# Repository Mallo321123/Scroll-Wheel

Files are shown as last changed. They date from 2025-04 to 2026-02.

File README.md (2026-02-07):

# 🖱️ High-Resolution Scroll Wheel

> A large, high-resolution scroll wheel inspired by [Engineer Bo](https://www.patreon.com/c/engineerbo/posts)'s [YouTube video](https://www.youtube.com/watch?v=FSy9G6bNuKA).

---

## [Documentation](https://wiki.mariolanghammer.de/en/Projects/Scroll-Wheel)

---

> ⚠️ **Early Development Phase**  
> This project is still under development. Use at your own risk.

---

## 📅 Roadmap

- [X] BLE HID Support
- [ ] Mouse Wheel Click Functionality
- [ ] Automatic power off
- [ ] Battery Level tuning
- [ ] Enclosure refinements
- [ ] Scroll acceleration modes

---

## 🔧 Hardware Overview

- **Main Controller:** ESP32 (subject to maybe change later)
- **Magnetic Encoder:** [AS5600](https://ams-osram.com/products/sensor-solutions/position-sensors/ams-as5600-position-sensor)
- **Battery Pack:** S3P2 NiMH Eneloop cells

---

## 💻 Software Architecture

The entire functionality is now handled by a single **ESP32 microcontroller** using **BLE HID** (Human Interface Device) mode.

- The scroll wheel inputs are directly interpreted by the ESP32.
- Input data (e.g. rotation) is sent over **Bluetooth Low Energy** as **HID events**, emulating a native scroll device.
- No additional driver or software is needed on the PC — it works like a standard Bluetooth mouse/scroll input.

> ✅ This simplifies the setup significantly and increases compatibility across Linux, Windows, and macOS.

---

## 🧩 Required Components

| Part | Quantity |
|---|---|
| Main PCB (pre-soldered) | 1 |
| Bearing (65×85×10 mm) | 1 |
| JST GH Cable Kit | 1 set |
| Cylinder Magnets (3×12 mm) | 7 |
| 3D-Printed Parts | 3 |
| S3P2 NiMH Battery Pack | 1 |
| M2×5 Screws | 5 |

---

## 🛠️ Build Guide

### 🔄 Bearing Preparation

Factory bearings may feel stiff due to thick grease. Here's how to optimize smoothness:

1. Remove both sealing rings.
2. Soak the bearing in **isopropyl alcohol** (or another grease remover).
3. Scrub out all remaining grease.
4. Let it dry for ~3 hours.
5. Reinstall **one** sealing ring.
6. Add **light machine oil** generously into the bearing.
7. Reinstall the **second** sealing ring.
8. Spin the bearing multiple times to distribute the oil.
9. *(Optional)* Remove the seals again for an even smoother feel (at the cost of dust protection).

---

## 🚧 Development Gallery

### 🔌 First PCB Prototype (with known bugs)
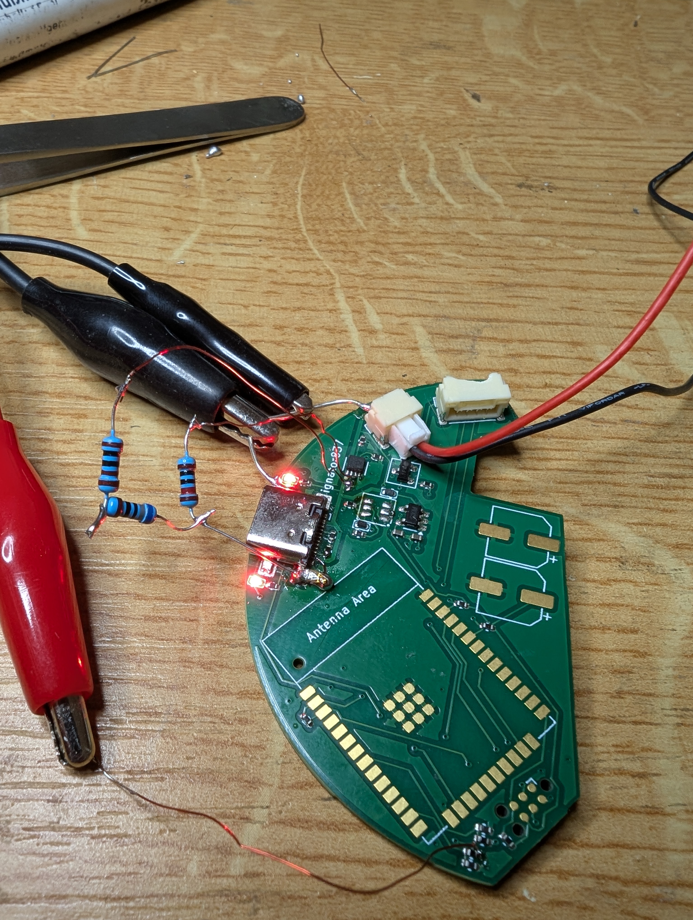
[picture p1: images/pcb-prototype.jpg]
First PCB prototype


---

### 🧱 PCB Inside the Case
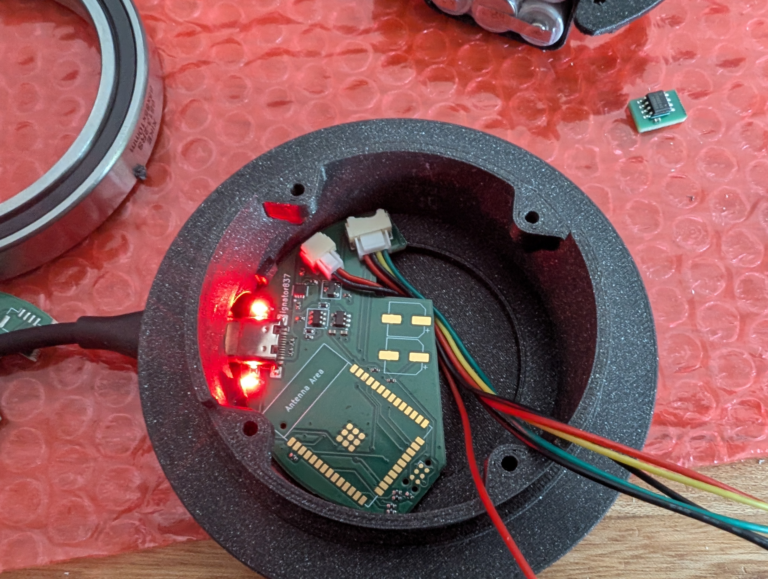
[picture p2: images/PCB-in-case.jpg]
PCB Prototype in case


---

### 🧪 First Firmware Test (External ESP32)
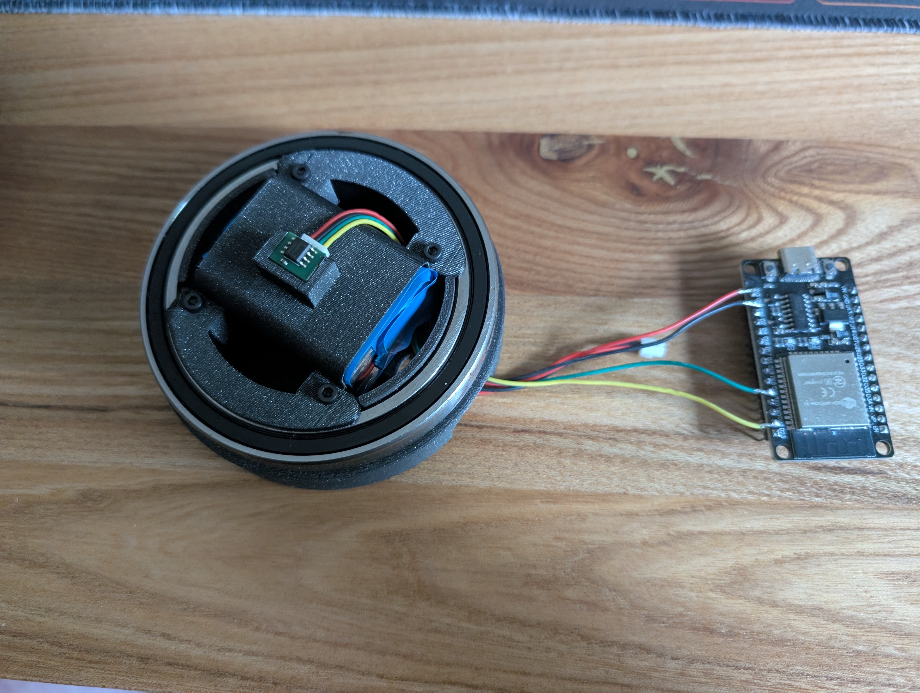
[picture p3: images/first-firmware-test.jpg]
Firmware test


---

### 🧰 Fully Assembled PCB
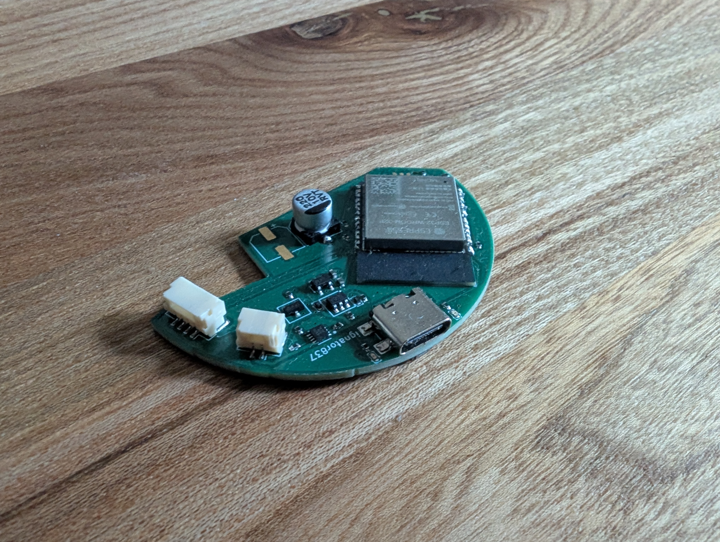
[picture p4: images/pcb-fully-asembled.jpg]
PCB Assembled


---

### 🆕 PCB V2 – Improved & Debugged
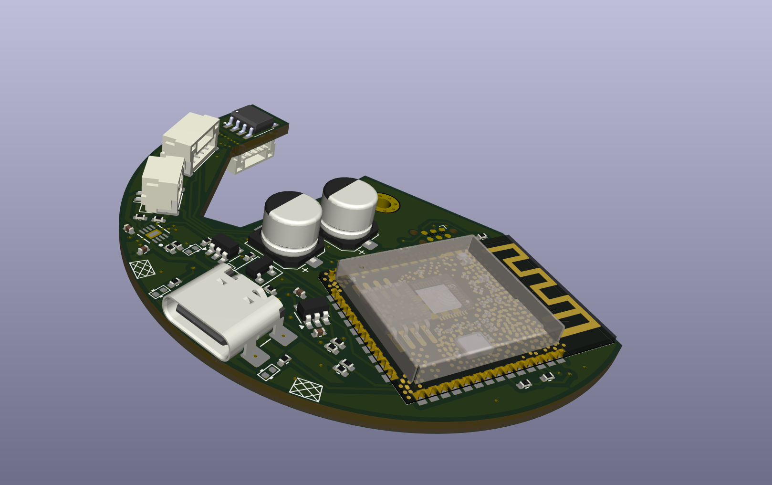
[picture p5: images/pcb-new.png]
PCB V2


---

## 🤝 Contributing

Pull requests, suggestions, and feedback are always welcome — feel free to get involved and help improve the project!  
Prototyping and hardware development can get expensive quickly, so if you’d like to support the project financially:

<a href="https://www.paypal.me/MarioLanghammer" target="_blank">
  
</a>
&nbsp;
<a href="https://ko-fi.com/mallo321123" target="_blank">
  
</a>

Every bit helps keep the ideas (and soldering irons) running!

## Credits
Credits to [T-vk](https://github.com/T-vK) for creating the [ESP32 BLE Mouse](https://github.com/T-vK/ESP32-BLE-Mouse) Library

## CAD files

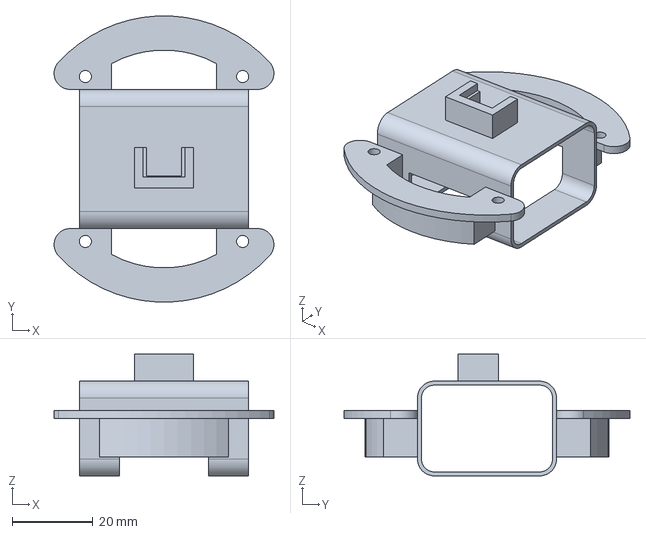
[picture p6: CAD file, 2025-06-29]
CAD/Component Bracket.step
54.5 x 70.9 x 30.2 mm

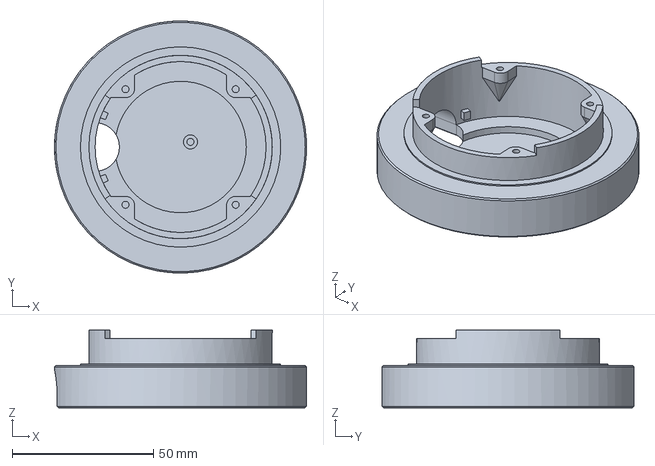
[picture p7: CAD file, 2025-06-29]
CAD/Bottom.step
89.3 x 89.4 x 27.5 mm

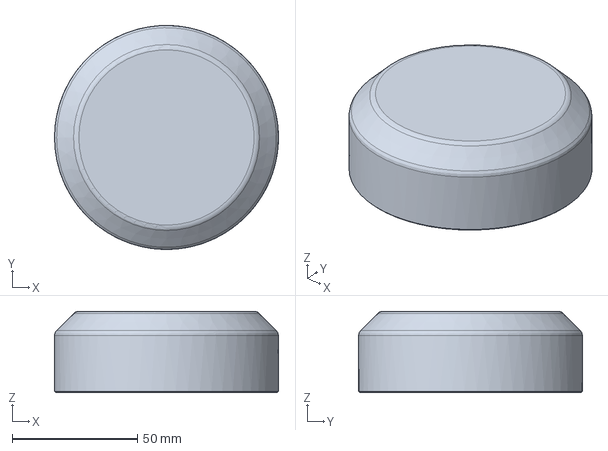
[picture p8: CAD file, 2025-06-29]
CAD/Cap.step
89.4 x 89.4 x 32.5 mm

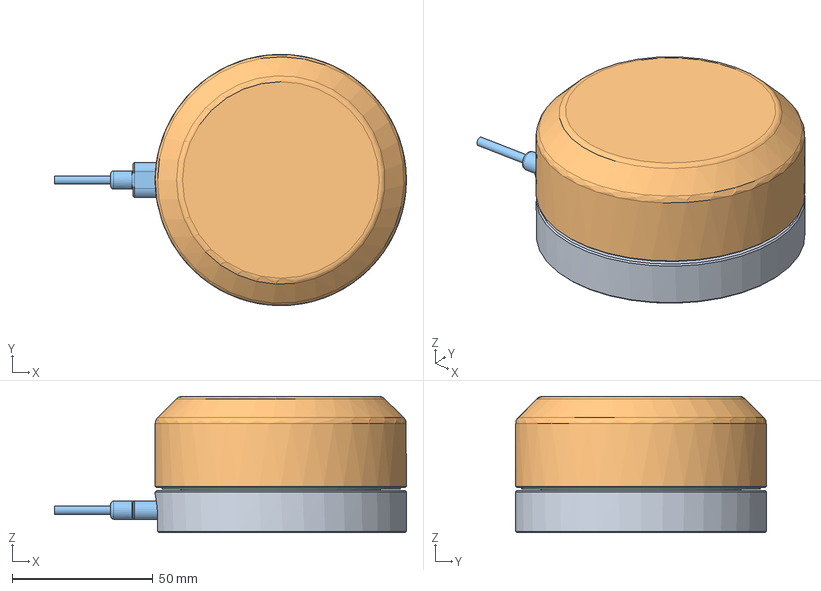
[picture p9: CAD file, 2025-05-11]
CAD/Body.FCStd
125.2 x 89.4 x 48.5 mm
Bottom
Cap
USB-Kabel
Bearing
R_0402_1005Metric
R_0402_1005Metric001
R_0402_1005Metric002
R_0402_1005Metric003
R_0402_1005Metric004
JST_GH_SM02B-GHS-TB_1x02-1MP_P1.25mm_Horizontal
R_0402_1005Metric005
R_0402_1005Metric006
SOT-23-5
R_0402_1005Metric007
DIO_RB161QS_ROM
DIO_RB161QS_ROM001
DIO_RB161QS_ROM002
DIO_RB161QS_ROM003
R_0402_1005Metric008
R_0402_1005Metric009
C_0402_1005Metric
CP_Elec_6.3x5.4
C_0402_1005Metric001
C_0402_1005Metric002
R_0402_1005Metric010
R_0402_1005Metric011
R_0402_1005Metric012
BODY-SON
R_0402_1005Metric013
AS5600
AS5601
AS5602
AS5603
AS5604
AS5605
AS5606
AS5607
AS5608
AS5609
SOT-23-6
R_0402_1005Metric014
R_0402_1005Metric015
JST_GH_SM04B-GHS-TB_1x04-1MP_P1.25mm_Horizontal
CP_Elec_6.3x5.005
DIO_RB161QS_ROM005
DIO_RB161QS_ROM006
DIO_RB161QS_ROM007
DIO_RB161QS_ROM008
R_0402_1005Metric016
SOT-23
R_0402_1005Metric017
USB_C_Receptacle_16P_TopMnt_Horizontal_GCT_USB4105-xx-A037
USB_C_Receptacle_16P_TopMnt_Horizontal_GCT_USB4105-xx-A038
USB_C_Receptacle_16P_TopMnt_Horizontal_GCT_USB4105-xx-A039
USB_C_Receptacle_16P_TopMnt_Horizontal_GCT_USB4105-xx-A040
USB_C_Receptacle_16P_TopMnt_Horizontal_GCT_USB4105-xx-A041
USB_C_Receptacle_16P_TopMnt_Horizontal_GCT_USB4105-xx-A042
USB_C_Receptacle_16P_TopMnt_Horizontal_GCT_USB4105-xx-A043
USB_C_Receptacle_16P_TopMnt_Horizontal_GCT_USB4105-xx-A044
USB_C_Receptacle_16P_TopMnt_Horizontal_GCT_USB4105-xx-A045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

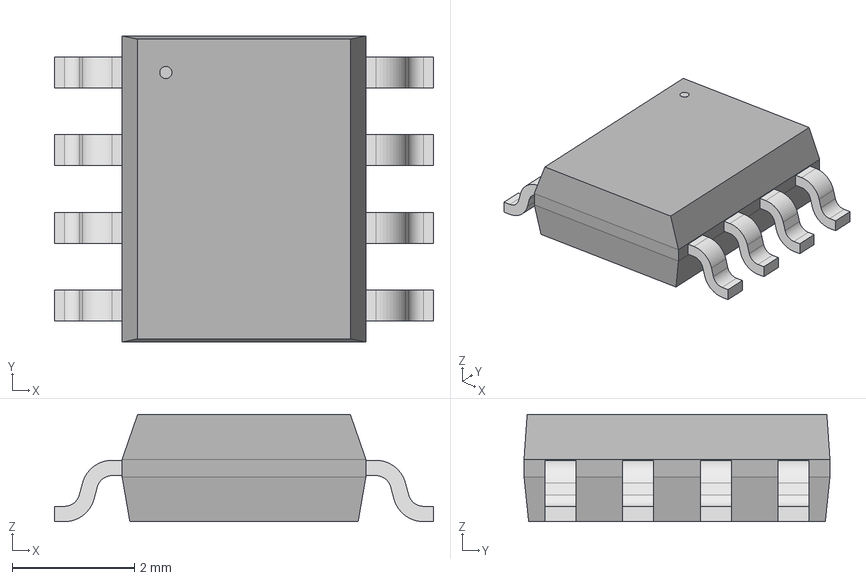
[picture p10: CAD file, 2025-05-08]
PCB/Librarys/3d/SO_ADY-T1-GE3_VIS.step
6.20 x 5.00 x 1.75 mm

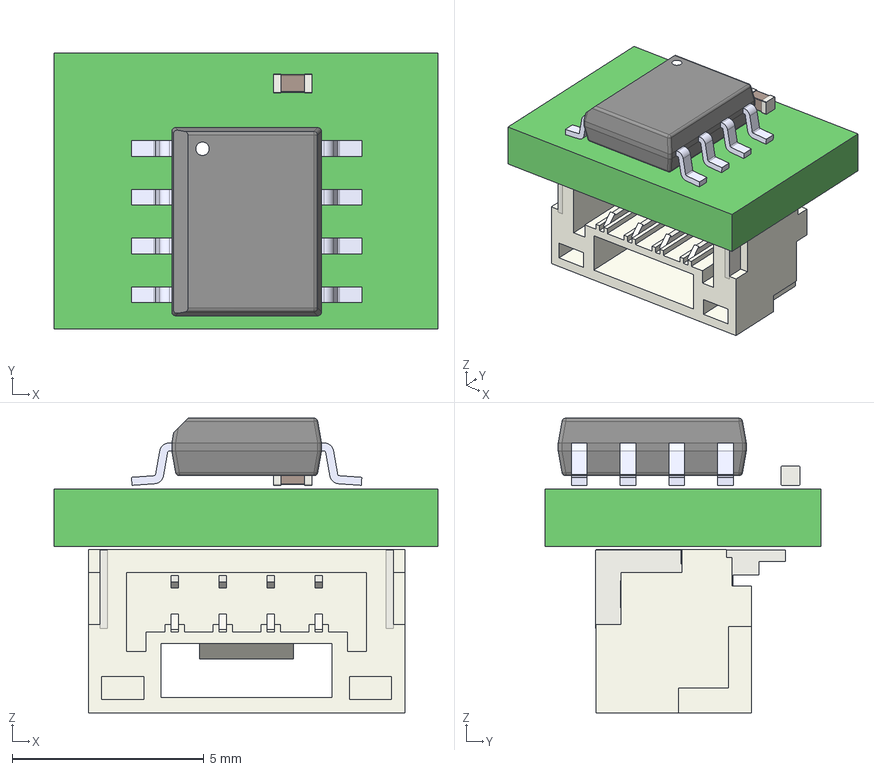
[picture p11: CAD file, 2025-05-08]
CAD/Encoder PCB.step
10.0 x 7.20 x 7.68 mm
C_0402_1005Metric001
AS5600
AS5601
AS5602
AS5603
AS5604
AS5605
AS5606
AS5607
AS5608
AS5609
JST_GH_SM04B-GHS-TB_1x04-1MP_P1.25mm_Horizontal001
Körper

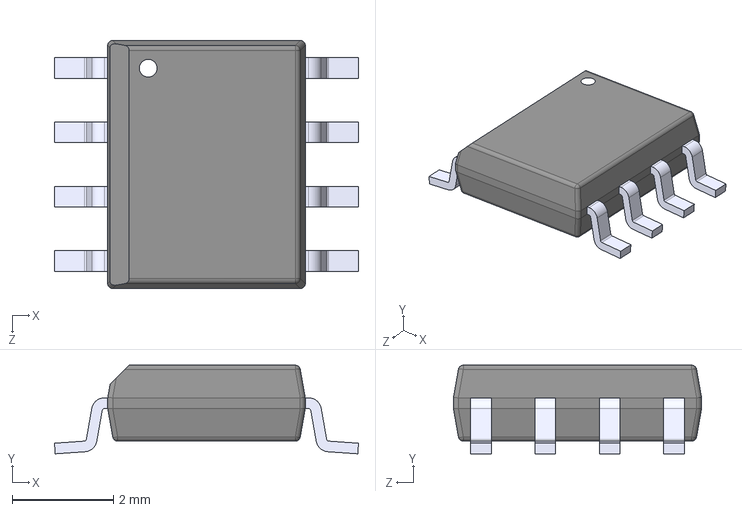
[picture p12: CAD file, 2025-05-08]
PCB/Librarys/3d/AS5600.step
6.00 x 1.75 x 4.90 mm

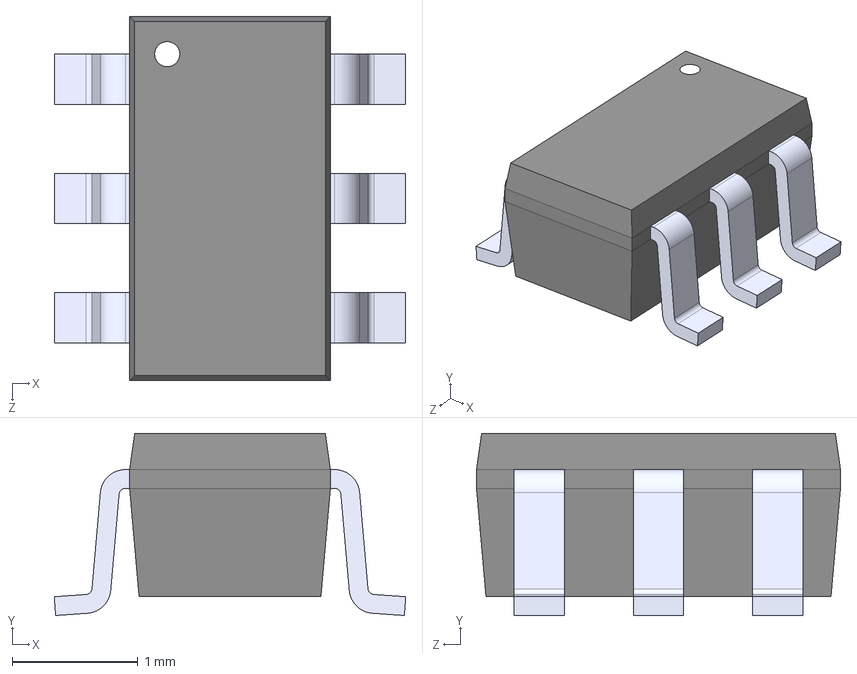
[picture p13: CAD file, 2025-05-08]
PCB/Librarys/3d/FS8205--3DModel.STEP
2.80 x 1.45 x 2.90 mm

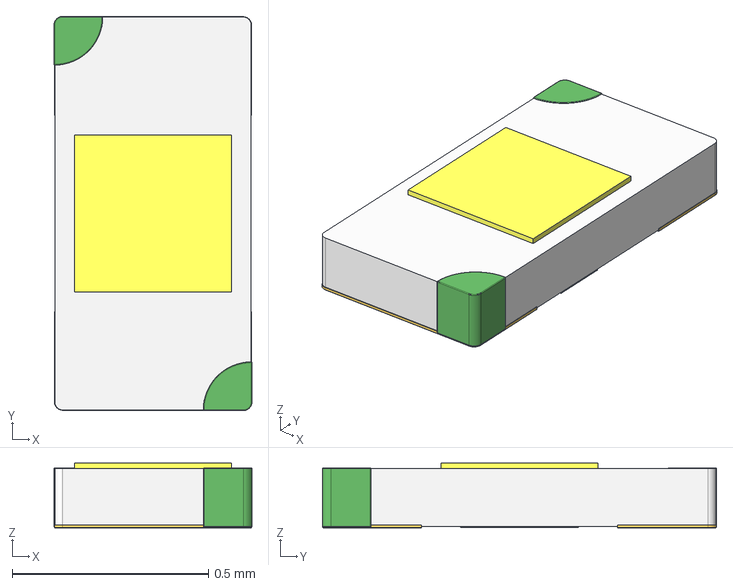
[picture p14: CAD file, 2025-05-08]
PCB/Librarys/3d/ChipLedWith-Yellow.stp
0.504 x 1.00 x 0.165 mm

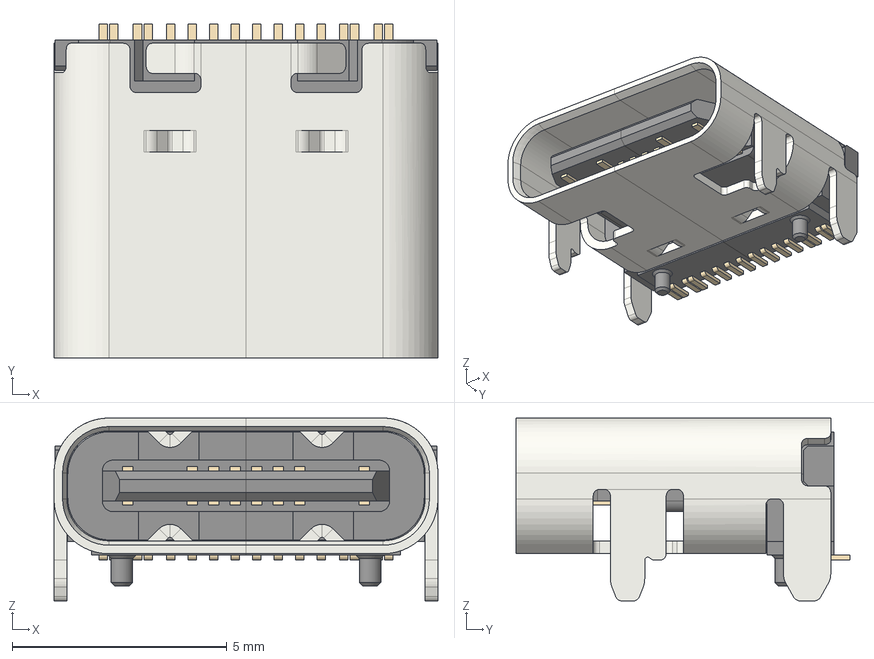
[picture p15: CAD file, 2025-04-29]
PCB/Librarys/3d/USB-C.step
8.94 x 7.78 x 4.26 mm
USB_C_Receptacle_16P_TopMnt_Horizontal_GCT_USB4105-xx-A037
USB_C_Receptacle_16P_TopMnt_Horizontal_GCT_USB4105-xx-A038
USB_C_Receptacle_16P_TopMnt_Horizontal_GCT_USB4105-xx-A039
USB_C_Receptacle_16P_TopMnt_Horizontal_GCT_USB4105-xx-A040
USB_C_Receptacle_16P_TopMnt_Horizontal_GCT_USB4105-xx-A041
USB_C_Receptacle_16P_TopMnt_Horizontal_GCT_USB4105-xx-A042
USB_C_Receptacle_16P_TopMnt_Horizontal_GCT_USB4105-xx-A043
USB_C_Receptacle_16P_TopMnt_Horizontal_GCT_USB4105-xx-A044
USB_C_Receptacle_16P_TopMnt_Horizontal_GCT_USB4105-xx-A045
USB_C_Receptacle_16P_TopMnt_Horizontal_GCT_USB4105-xx-A046
USB_C_Receptacle_16P_TopMnt_Horizontal_GCT_USB4105-xx-A047
USB_C_Receptacle_16P_TopMnt_Horizontal_GCT_USB4105-xx-A048
USB_C_Receptacle_16P_TopMnt_Horizontal_GCT_USB4105-xx-A049
USB_C_Receptacle_16P_TopMnt_Horizontal_GCT_USB4105-xx-A050
USB_C_Receptacle_16P_TopMnt_Horizontal_GCT_USB4105-xx-A051
USB_C_Receptacle_16P_TopMnt_Horizontal_GCT_USB4105-xx-A052
USB_C_Receptacle_16P_TopMnt_Horizontal_GCT_USB4105-xx-A053
USB_C_Receptacle_16P_TopMnt_Horizontal_GCT_USB4105-xx-A054
USB_C_Receptacle_16P_TopMnt_Horizontal_GCT_USB4105-xx-A055
USB_C_Receptacle_16P_TopMnt_Horizontal_GCT_USB4105-xx-A056
USB_C_Receptacle_16P_TopMnt_Horizontal_GCT_USB4105-xx-A057
USB_C_Receptacle_16P_TopMnt_Horizontal_GCT_USB4105-xx-A058
USB_C_Receptacle_16P_TopMnt_Horizontal_GCT_USB4105-xx-A059
USB_C_Receptacle_16P_TopMnt_Horizontal_GCT_USB4105-xx-A060
USB_C_Receptacle_16P_TopMnt_Horizontal_GCT_USB4105-xx-A061
USB_C_Receptacle_16P_TopMnt_Horizontal_GCT_USB4105-xx-A062
USB_C_Receptacle_16P_TopMnt_Horizontal_GCT_USB4105-xx-A063
USB_C_Receptacle_16P_TopMnt_Horizontal_GCT_USB4105-xx-A064
USB_C_Receptacle_16P_TopMnt_Horizontal_GCT_USB4105-xx-A065
USB_C_Receptacle_16P_TopMnt_Horizontal_GCT_USB4105-xx-A066
USB_C_Receptacle_16P_TopMnt_Horizontal_GCT_USB4105-xx-A067
USB_C_Receptacle_16P_TopMnt_Horizontal_GCT_USB4105-xx-A068
USB_C_Receptacle_16P_TopMnt_Horizontal_GCT_USB4105-xx-A069
USB_C_Receptacle_16P_TopMnt_Horizontal_GCT_USB4105-xx-A070
USB_C_Receptacle_16P_TopMnt_Horizontal_GCT_USB4105-xx-A071
USB_C_Receptacle_16P_TopMnt_Horizontal_GCT_USB4105-xx-A072

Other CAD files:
PCB/Librarys/3d/TS-1088-AR02016--3DModel-STEP-269445.STEP
PCB/Librarys/3d/DSG0008A.stp
PCB/Librarys/3d/DIO_RB161QS_ROM.step
CAD/Bottom.stl
CAD/Cap.stl
CAD/Component Bracket.stl

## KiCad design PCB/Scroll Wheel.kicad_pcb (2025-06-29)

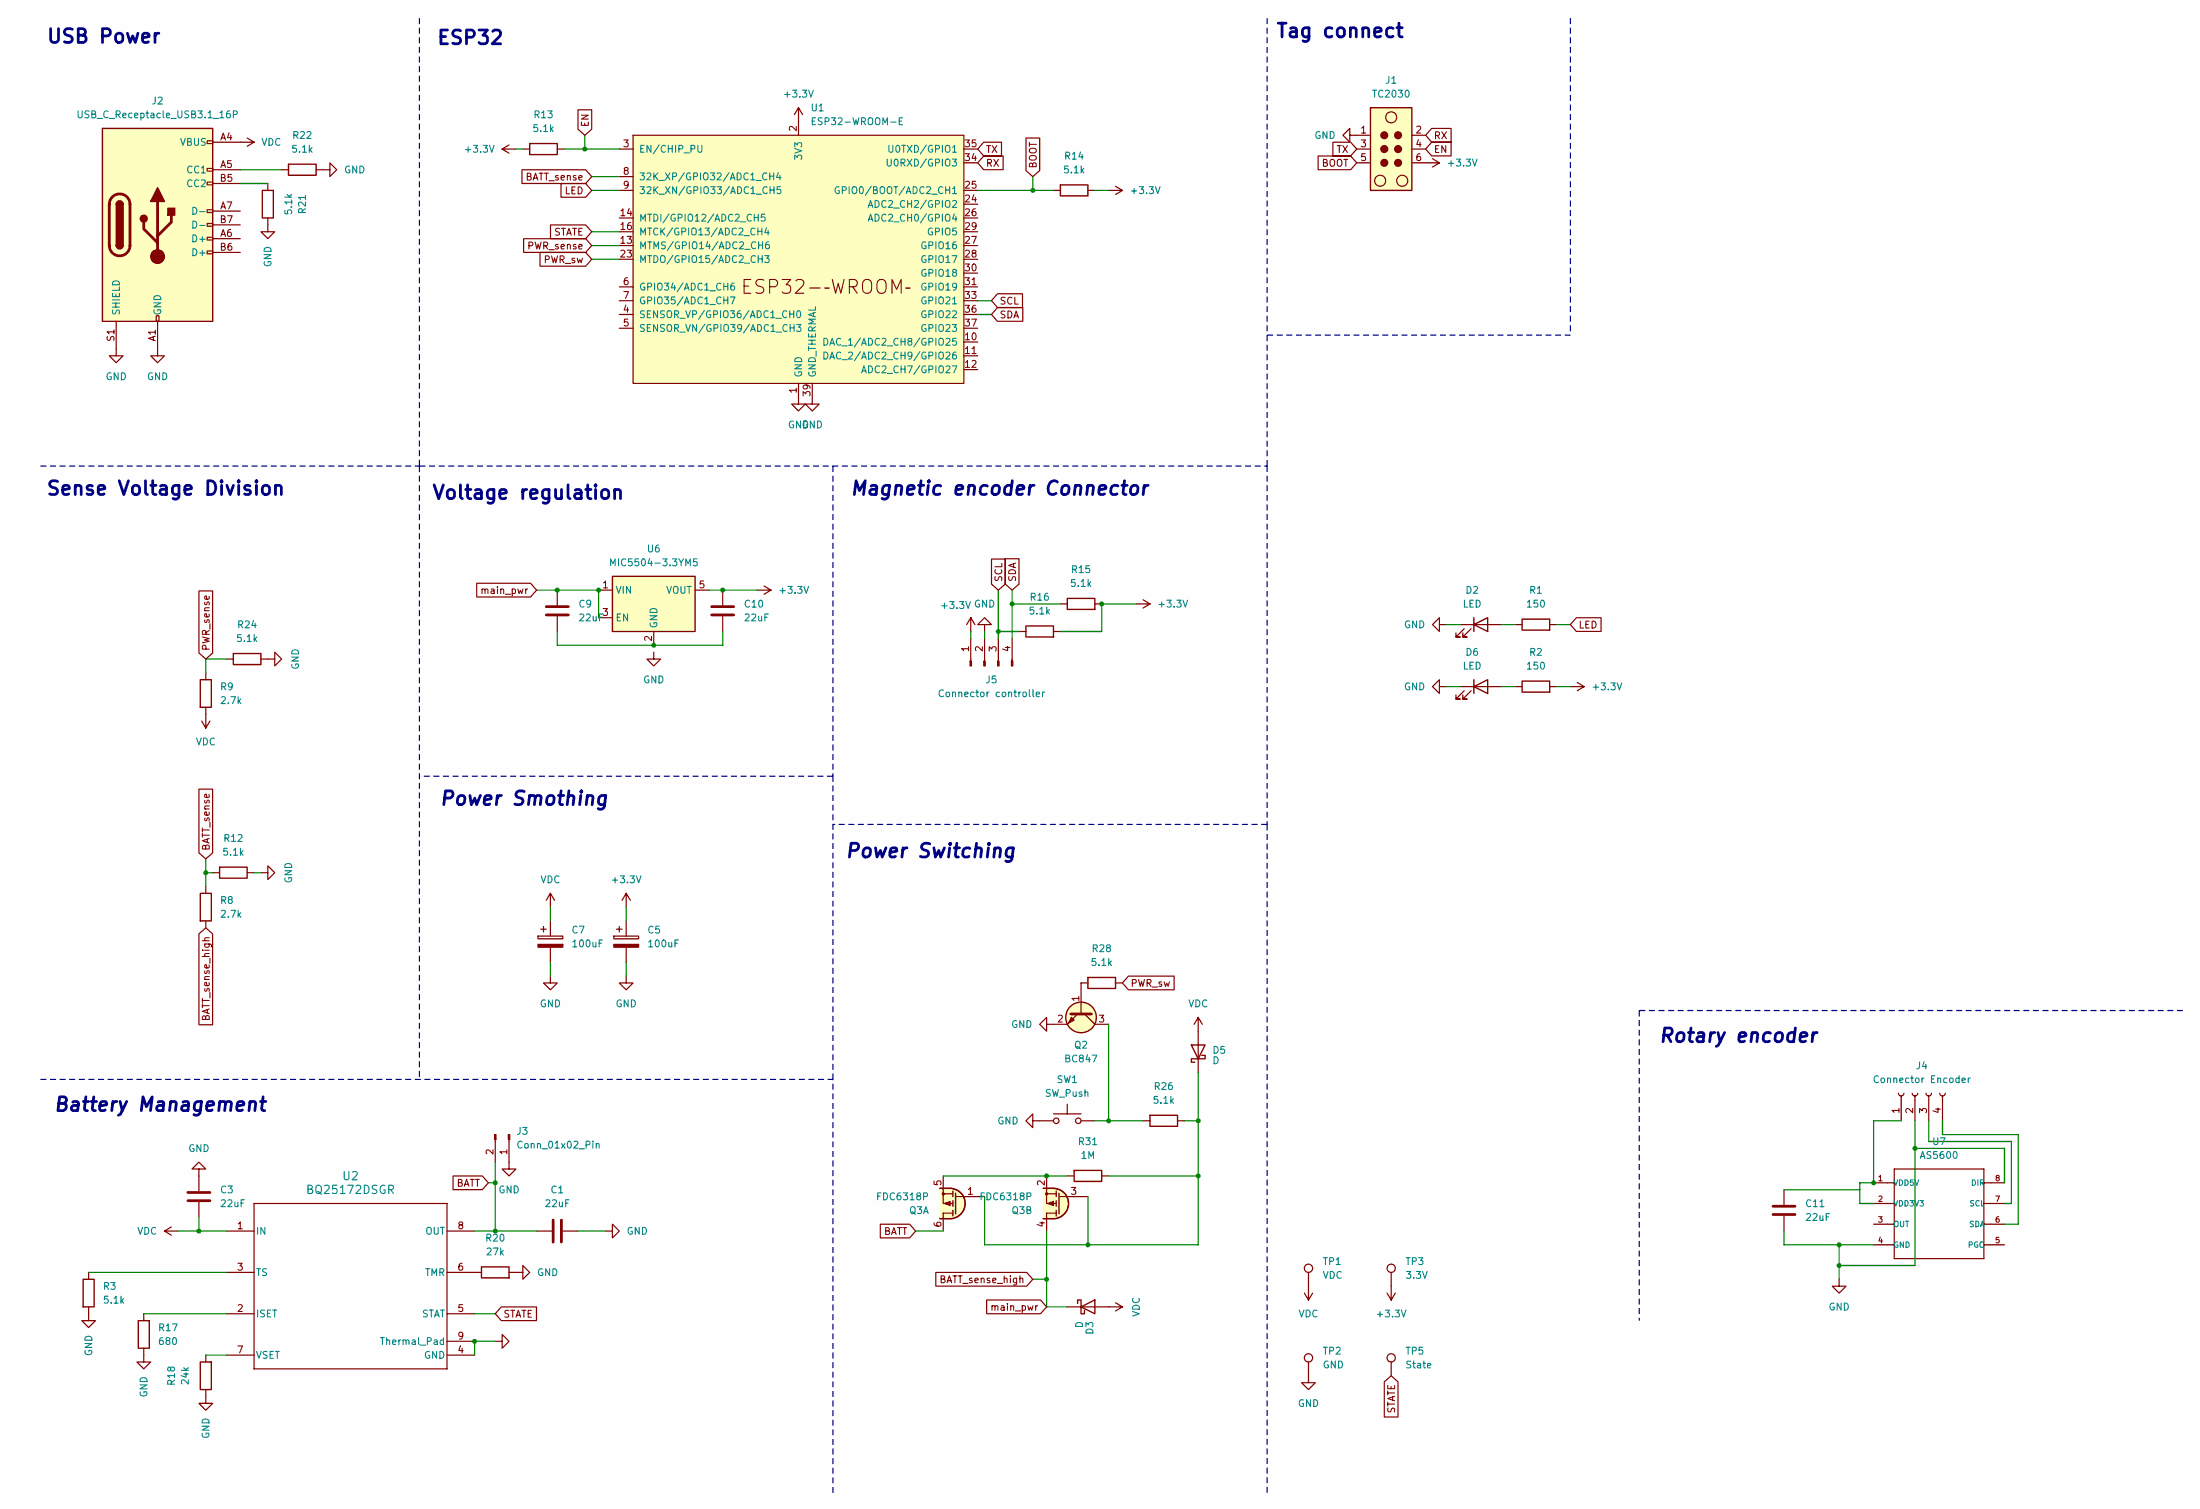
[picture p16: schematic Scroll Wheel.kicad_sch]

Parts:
C1, C3, C9, C10, C11: 22uF; C_0402_1005Metric; LCSC C22367823
C5, C7: 100uF; CP_Elec_6.3x5.4; LCSC C72494
D2, D6: LED; D_0402_1005Metric; LCSC C397045
D3, D5: D; D_0402_1005Metric; LCSC C28646385
J1: TC2030; Tag-Connect_TC2030-IDC-NL_2x03_P1.27mm_Vertical
J2: USB_C_Receptacle_USB3.1_16P; USB_C_Receptacle_GCT_USB4110; LCSC C5187472
J3: Conn_01x02_Pin; JST_GH_SM02B-GHS-TB_1x02-1MP_P1.25mm_Horizontal; LCSC C189893
J4: Connector Encoder; JST_GH_SM04B-GHS-TB_1x04-1MP_P1.25mm_Horizontal; LCSC C189895
J5: Connector controller; JST_GH_SM04B-GHS-TB_1x04-1MP_P1.25mm_Horizontal; LCSC C189895
Q2: BC847; SOT-23; LCSC C57668
Q3: FDC6318P; SOT-23-6; LCSC C7472919
R1, R2: 150; R_0402_1005Metric; LCSC C138054
R3, R12, R13, R14, R15, R16, R21, R22, R24, R26, R28: 5.1k; R_0402_1005Metric; LCSC C25905
R8, R9: 2.7k; R_0402_1005Metric; LCSC C138017
R17: 680; R_0402_1005Metric; LCSC C137948
R18: 24k; R_0402_1005Metric; LCSC C2933082
R20: 27k; R_0402_1005Metric; LCSC C138022
R31: 1M; R_0402_1005Metric; LCSC C138033
SW1: SW_Push; SW_Push_SPST_NO_Alps_SKRK; LCSC C720477
TP1: VDC; TestPoint_Pad_D1.0mm
TP2: GND; TestPoint_Pad_D1.0mm
TP3: 3.3V; TestPoint_Pad_D1.0mm
TP5: State; TestPoint_Pad_D1.0mm
U1: ESP32-WROOM-E; ESP32-WROOM-32E; LCSC C701342
U2: BQ25172DSGR; DSG0008A-IPC_A; LCSC C5189434
U6: MIC5504-3.3YM5; SOT-23-5; LCSC C41348078
U7: AS5600; LCSC C499458

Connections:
+3.3V: C5.1, C10.2, J1.6, J5.1, R2.2, R13.2, R14.1, R15.2, R16.2, TP3.1, U1.2 (3V3), U6.5 (VOUT)
BATT: C1.2, J3.2, Q3.6 (D1), U2.8 (OUT)
BATT_sense: R8.1, R12.2, U1.8 (32K_XP/GPIO32/ADC1_CH4)
BATT_sense_high: C9.2, D3.1 (K), Q3.4 (D2), R8.2, U6.1 (VIN), U6.3 (EN)
BOOT: J1.5, R14.2, U1.25 (GPIO0/BOOT/ADC2_CH1)
EN: J1.4, R13.1, U1.3 (EN/CHIP_PU)
GND: C1.1, C3.2, C5.2, C7.2, C11.1, D2.1 (K), D6.1 (K), J1.1, J2.A1 (GND), J2.A12 (GND), J2.B1 (GND), J2.B12 (GND), J2.S1 (SHIELD), J3.1, J3.MP, J4.2, J4.MP, J5.2, J5.MP, Q2.2 (E), R3.2, R12.1, R17.1, R18.1, R20.2, R21.1, R22.1, R24.1, SW1.1, TP2.1, U1.1 (GND), U1.15 (GND), U1.38 (GND), U1.39 (GND_THERMAL), U2.4 (GND), U2.9 (Thermal_Pad), U7.4 (GND), U7.8 (DIR)
LED: R1.2, U1.9 (32K_XN/GPIO33/ADC1_CH5)
unnamed: D2.2 (A), R1.1
unnamed: D5.1 (K), Q3.1 (G1), Q3.3 (G2), R26.1, R31.1
unnamed: D6.2 (A), R2.1
unnamed: J2.A5 (CC1), R22.2
unnamed: J2.B5 (CC2), R21.2
unnamed: C11.2, J4.1, U7.1 (VDD5V), U7.2 (VDD3V3)
unnamed: J4.3, U7.7 (SCL)
unnamed: J4.4, U7.6 (SDA)
unnamed: Q2.1 (B), R28.2
unnamed: Q2.3 (C), R26.2, SW1.2
unnamed: Q3.2 (S2), Q3.5 (S1), R31.2
unnamed: R17.2, U2.2 (ISET)
unnamed: R20.1, U2.6 (TMR)
unnamed: R3.1, U2.3 (TS)
unnamed: R18.2, U2.7 (VSET)
unnamed: C9.1, C10.1, U6.2 (GND)
PWR_sense: R9.1, R24.2, U1.13 (MTMS/GPIO14/ADC2_CH6)
PWR_sw: R28.1, U1.23 (MTDO/GPIO15/ADC2_CH3)
RX: J1.2, U1.34 (U0RXD/GPIO3)
SCL: J5.3, R16.1, U1.33 (GPIO21)
SDA: J5.4, R15.1, U1.36 (GPIO22)
STATE: TP5.1, U1.16 (MTCK/GPIO13/ADC2_CH4), U2.5 (STAT)
TX: J1.3, U1.35 (U0TXD/GPIO1)
VDC: C3.1, C7.1, D3.2 (A), D5.2 (A), J2.A4 (VBUS), J2.A9 (VBUS), J2.B4 (VBUS), J2.B9 (VBUS), R9.2, TP1.1, U2.1 (IN)

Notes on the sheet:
Battery Management
Power Smothing
Magnetic encoder Connector
Rotary encoder
USB Power
ESP32
Power Switching
Sense Voltage Division
Voltage regulation
Tag connect

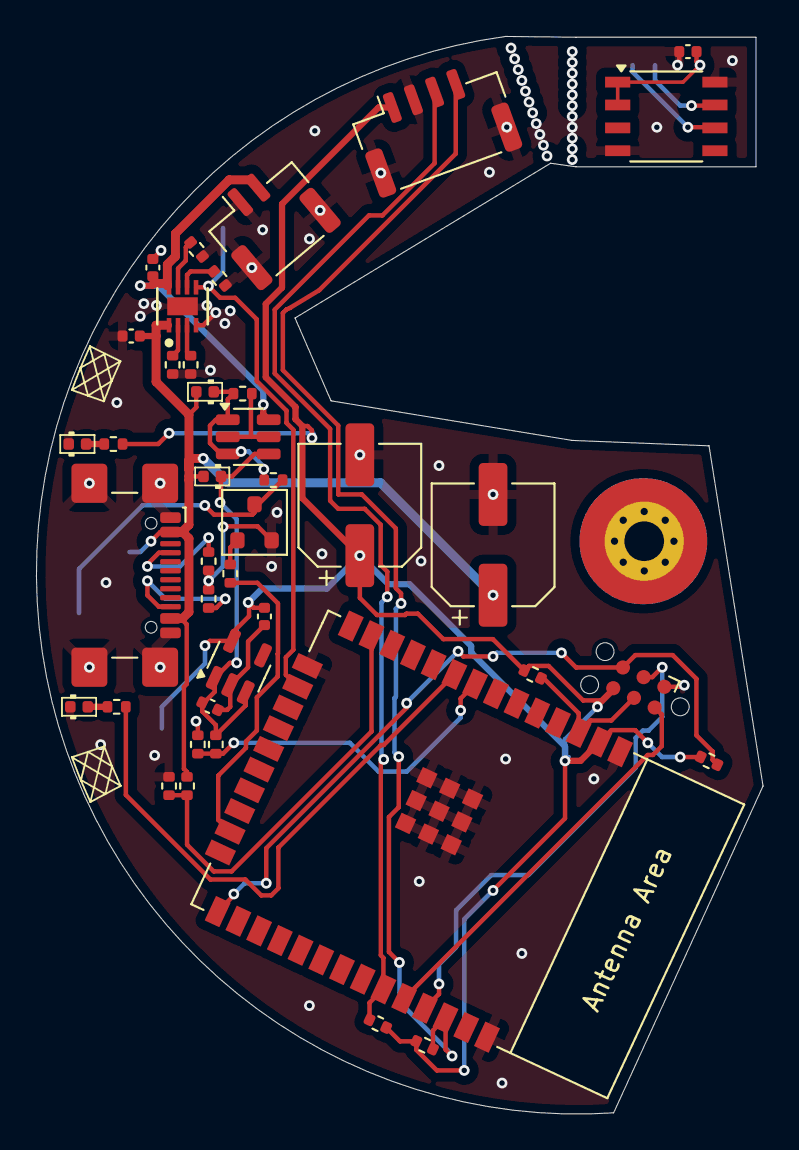
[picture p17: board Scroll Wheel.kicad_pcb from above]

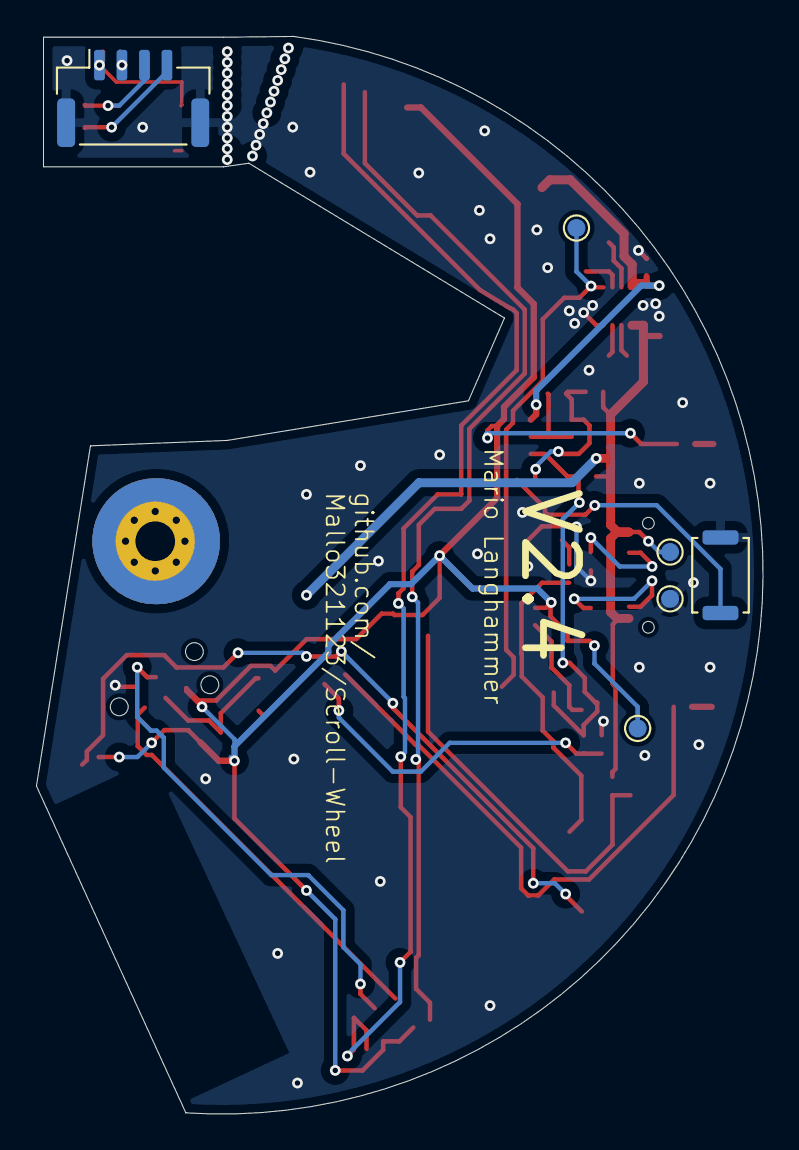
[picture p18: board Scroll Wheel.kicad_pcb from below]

Board: 2 copper layers, 40.4 x 59.9 mm, 46 parts (6 on the bottom side), 32 nets.

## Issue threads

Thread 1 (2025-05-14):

Missing GND plane connections

Mallo321123, 2025-05-14:
Some GND planes are not connected

Closed 2025-05-14.

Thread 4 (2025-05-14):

Add 10k pulldown to TS pin of BQ25172

Mallo321123, 2025-05-14:
Add the missing 10k pulldown

Closed 2025-05-14.

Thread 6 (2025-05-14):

Connect +5 Pad of Smoothing cap

Mallo321123, 2025-05-14:
The +5 connection of the Smoothing capacitor is missing for some reason

Closed 2025-05-14.

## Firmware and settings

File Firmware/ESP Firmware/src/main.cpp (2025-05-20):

#include <Arduino.h>
#include <BLEDevice.h>
#include <BLEServer.h>
#include <BLEUtils.h>
#include <BLE2902.h>
#include <Wire.h>
#include <AS5600.h>

#define FIRMWARE_VERSION "0.1.0"

#define SERVICE_UUID "6E400001-B5A3-F393-E0A9-E50E24DCCA9E"      // UART Service
#define CHARACTERISTIC_RX "6E400002-B5A3-F393-E0A9-E50E24DCCA9E" // RX Characteristic
#define CHARACTERISTIC_TX "6E400003-B5A3-F393-E0A9-E50E24DCCA9E" // TX Characteristic

#define BLE_DEVICE_NAME "Scroll Wheel" // Name of the BLE device

#define LOOP_SLEEP_TIME 10        // Sleep time in ms
#define RECONNECT_SLEEP_TIME 1000 // Sleep time in ms

#define SCROLL_UPDATE_INTERVAL 100 // Interval for scroll value update in ms

#define BATTERY_UPDATE_INTERVAL 5000 // Set battery update interval in s
#define BATTERY_MAX_VOLTAGE 4.2      // Maximal Battery Voltage
#define BATTERY_MIN_VOLTAGE 3.3      // Minimal Battery Voltage
#define BATTERY_VALUE_CORRECTION 1   // Battery value correction

#define PWR_SW_PIN 15             // Needs to be high for device to stay on
#define BATTERY_SENSE_PIN 32      // ADC pin for battery voltage sensing
#define POWER_SENSE_PIN 14        // ADC pin for sensing connected USB
#define CHARGE_STATE_SENSE_PIN 13 // ADC pin for sensing charge state

#define SCROLL_MULTIPLICATOR 1    // Multiplier for scroll value
#define JITTER_THRESHOLD 0.5      // Threshold for jitter in scroll angle
#define MAX_ROTATION_PER_READ 180 // Maximal rotation per read in degrees

BLEServer *pServer = NULL;
BLECharacteristic *pTxCharacteristic = NULL;
bool deviceConnected = false;
bool oldDeviceConnected = false;
unsigned long lastScrollUpdate = 0;
unsigned long lastBatteryTime = 0;

float angle_before = 380.0; // Initial angle

AS5600 encoder;

// Callback for BLE server connection
class MyServerCallbacks : public BLEServerCallbacks
{
  void onConnect(BLEServer *pServer)
  {
    deviceConnected = true;
    Serial.println("Client connected");
  };

  void onDisconnect(BLEServer *pServer)
  {
    deviceConnected = false;
    Serial.println("Client disconnected");
  }
};

// Callback for received data
class MyCallbacks : public BLECharacteristicCallbacks
{
  void onWrite(BLECharacteristic *pCharacteristic)
  {
    std::string rxValue = pCharacteristic->getValue();

    if (rxValue.length() > 0)
    {
      Serial.println("Recieved from client:");
      for (int i = 0; i < rxValue.length(); i++)
      {
        Serial.print(rxValue[i]);
      }
      Serial.println();
    }
  }
};

int getBatteryLevel()
{
  // read raw value from ADC
  int rawValue = analogRead(BATTERY_SENSE_PIN);
  float voltage = rawValue * (3.3 / 4095.0) * BATTERY_VALUE_CORRECTION;

  // Pcalculate battery percentage
  int percentage = map(voltage * 100,
                       BATTERY_MIN_VOLTAGE * 100,
                       BATTERY_MAX_VOLTAGE * 100,
                       0,
                       100);

  // limit percentage to 0-100
  percentage = constrain(percentage, 0, 100);

  return percentage;
}

int getScrollValue()
{
  int rawAngle = encoder.readAngle(); // Value between 0 and 4095 (12-bit)
  float angleDeg = rawAngle * 360.0 / 4096.0;

  // set first angle after boot
  if (angle_before == 380.0)
  {
    angle_before = angleDeg;
  }

  float angleDiff = angleDeg - angle_before;

  if (fabs(angleDiff) < JITTER_THRESHOLD)
  {
    return 0; // Ignore small changes
  }

  // Handle wrap-around at 0/360 degrees
  if (angleDiff > MAX_ROTATION_PER_READ)
  {
    angleDiff -= 360.0;
  }
  else if (angleDiff < -MAX_ROTATION_PER_READ)
  {
    angleDiff += 360.0;
  }

  // Store current angle for next comparison
  angle_before = angleDeg;

  // Scale and round the value as needed
  int scrollValue = round(angleDiff * SCROLL_MULTIPLICATOR);

  return scrollValue;
}

void setup()
{
  pinMode(PWR_SW_PIN, OUTPUT);
  digitalWrite(PWR_SW_PIN, HIGH); // Set PWR_SW_PIN high to keep the device on

  Serial.begin(115200);
  Serial.println("Scroll Wheel version " FIRMWARE_VERSION);
  Serial.println("Initializing...");

  pinMode(BATTERY_SENSE_PIN, INPUT);
  pinMode(POWER_SENSE_PIN, INPUT);
  pinMode(CHARGE_STATE_SENSE_PIN, INPUT);
  analogReadResolution(12);

  Wire.begin(22, 21);

  // BLE Initialisation
  BLEDevice::init(BLE_DEVICE_NAME);

  // Create Server
  pServer = BLEDevice::createServer();
  pServer->setCallbacks(new MyServerCallbacks());

  // create Service
  BLEService *pService = pServer->createService(SERVICE_UUID);

  // TX Charakteristics
  pTxCharacteristic = pService->createCharacteristic(
      CHARACTERISTIC_TX,
      BLECharacteristic::PROPERTY_NOTIFY);
  pTxCharacteristic->addDescriptor(new BLE2902());

  // RX Charakteristcs
  BLECharacteristic *pRxCharacteristic = pService->createCharacteristic(
      CHARACTERISTIC_RX,
      BLECharacteristic::PROPERTY_WRITE);
  pRxCharacteristic->setCallbacks(new MyCallbacks());

  // start service
  pService->start();

  // Start advertising
  BLEAdvertising *pAdvertising = BLEDevice::getAdvertising();
  pAdvertising->addServiceUUID(SERVICE_UUID);
  pAdvertising->setScanResponse(true);

  // Option for better visibility for android and IOS
  /*pAdvertising->setMinPreferred(0x06);
  pAdvertising->setMaxPreferred(0x12);*/

  BLEDevice::startAdvertising();

  if (!encoder.begin())
  {
    Serial.println("Rotary encoder not found!");
    while (1)
      ;
  }
  Serial.println("Encoder initialized");

  Serial.println("Scroll Wheel ready, waiting for client...");
}

void loop()
{
  // Regularly send scroll value
  if (deviceConnected && (millis() - lastScrollUpdate >= SCROLL_UPDATE_INTERVAL))
  {
    lastScrollUpdate = millis();

    // read sensor value
    int value = getScrollValue();
    char buffer[32];

    if (!(value == 0))
    {
      snprintf(buffer, sizeof(buffer), "SCR:%d", value);

      // Send value as notification
      pTxCharacteristic->setValue(buffer);
      pTxCharacteristic->notify();
    }
  }

  // Regularly send battery level
  if (deviceConnected && (millis() - lastBatteryTime >= BATTERY_UPDATE_INTERVAL))
  {
    lastBatteryTime = millis();

    // Read battery level
    int batteryLevel = getBatteryLevel();
    char buffer[32];
    snprintf(buffer, sizeof(buffer), "BAT:%d", batteryLevel);

    // send battery level as notification
    pTxCharacteristic->setValue(buffer);
    pTxCharacteristic->notify();

    Serial.printf("Akkuladung: %d%%\n", batteryLevel);
  }

  // Verbindungsstatus verwalten
  if (!deviceConnected && oldDeviceConnected)
  {
    // on reconnect we can start advertising again
    delay(RECONNECT_SLEEP_TIME);

    pServer->startAdvertising(); // Start advertising
    Serial.println("BLE advertising started");
    oldDeviceConnected = deviceConnected;
  }

  // Detect new connections
  if (deviceConnected && !oldDeviceConnected)
  {
    oldDeviceConnected = deviceConnected;
  }

  delay(LOOP_SLEEP_TIME);
}

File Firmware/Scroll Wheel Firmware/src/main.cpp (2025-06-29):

#include <Arduino.h>
#include <Wire.h>

#include "BleMouse.h"
#include "defaults.h"
#include "battery.h"
#include "main.h"
#include "globals.h"

unsigned long lastScrollUpdate = 0;
unsigned long lastBatteryTime = 0;

void setup()
{
    pinMode(PWR_SW_PIN, OUTPUT);
    digitalWrite(PWR_SW_PIN, HIGH); // Set PWR_SW_PIN high to keep the device on

    Serial.begin(115200);

    Serial.println("Scroll Wheel version " FIRMWARE_VERSION);
    Serial.println("Initializing...");

    bleMouse.begin();

    pinMode(BATTERY_SENSE_PIN, INPUT);
    pinMode(POWER_SENSE_PIN, INPUT);
    pinMode(CHARGE_STATE_SENSE_PIN, INPUT);
    analogReadResolution(12);

    Wire.begin(22, 21);

    if (!encoder.begin())
    {
        Serial.println("Rotary encoder not found!");
        while (1)
            ;
    }
    Serial.println("Scroll Wheel ready, waiting for client...");
}

void loop()
{
    if (bleMouse.isConnected() && (millis() - lastScrollUpdate >= SCROLL_UPDATE_INTERVAL))
    {
        lastScrollUpdate = millis();
        int value = getScrollValue();

        if (value != 0)
        {
            bleMouse.move(0, 0, value); // Send scroll value to BLE mouse
        }
    }
    delay(LOOP_SLEEP_TIME);
}

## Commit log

2025-04-29 Fix Custom Imports
    [AS5600.step]
2025-05-01 Battery Part Redesign
    [Scroll Wheel.kicad_pcb, Scroll Wheel.kicad_sch]
2025-05-01 basic cad model
    [Body.FCStd]
2025-05-05 fix NMOS to PMOS, and 3d Modells
    [AS5600.step, ChipLedWith-Yellow.stp, DIO_RB161QS_ROM.step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]
2025-05-08 Fix PCB libs
    [ChipLedWith-Yellow.stp, DIO_RB161QS_ROM.step, DSG0008A.stp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]
2025-05-08 Finish CAD Model
    [Body.FCStd, Bottom.step, Cap.step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]
2025-05-08 Fix Git fuckup
    [Scroll Wheel.kicad_sch]
2025-05-08 add Python driver
2025-05-08 add missing label
    [Scroll Wheel.kicad_pcb, Scroll Wheel.kicad_sch]
2025-05-10 add a skirt under the Bearing and tweak some tolerances
    [Body.FCStd, Bottom.step, Bottom.stl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]
2025-05-10 fix to tight tolerances between Bearing and Top
    [Body.FCStd, Bottom.stl, Cap.stl]
2025-05-11 better mounting for Bearing
    [Body.FCStd, Bottom.stl, Cap.stl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]
2025-05-11 replace charge state leds with power and status leds
    [Scroll Wheel.kicad_sch]
2025-05-14 Fix #5
    [Scroll Wheel.kicad_sch]
2025-05-14 Fix #3 and #4
    [Scroll Wheel.kicad_sch]
2025-05-14 Fix #7
    [Scroll Wheel.kicad_sch]
2025-05-14 change charge controller caps to known value
    [Scroll Wheel.kicad_sch]
2025-05-14 Complete rerouting, fixing all open issues #6 #2 #1
    [Scroll Wheel.kicad_pcb, Scroll Wheel.kicad_sch]
2025-05-20 add better PCB mounting solution in the Case
    [Bottom.step, Bottom.stl, Cap.step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]
2025-05-20 some fixing and value tweaking
    [main.cpp]
2025-05-20 add a better mounting solution
    [Scroll Wheel.kicad_pcb, Scroll Wheel.kicad_sch]
2025-06-25 add PCB-rendering image
2025-06-29 some CAD Improvements
    [Bottom.step, Bottom.stl, Cap.step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]
2025-06-29 generate new PCB Production files
    [Scroll Wheel.kicad_pcb]
2025-06-29 Switch from BLE Uart to BLE HID
2025-10-22 Add credits section to README
    Added credits section for T-vk and ESP32 BLE Mouse library.
